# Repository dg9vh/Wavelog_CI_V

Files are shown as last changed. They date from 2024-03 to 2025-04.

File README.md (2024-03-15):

# Wavelog_CI_V
image of configuration dialog on ESP32-webserver

## Introduction
This is a CI-V Connector for Wavelog that can be running on an ESP32 developer board.

## Needed hardware
* ESP 32 board
* 3,5 mm jack plug
* some wire
* diode
* 1x 4k7 resistor
* 1x 10k resistor

How a prototype of a pcb with ESP32 can look like

On the image above you see a prototype built on a perforated grid circuit board.

## Wiring schedule
[Schematics.pdf](/Documents/Schematics.pdf)

## Features
This connects via CI-V to your Icom Transceiver (e.g. IC-7300) on the 3,5 mm jack plug port.
From there it reads following measurements:
* Working frequency
* Working mode
* Working rf-power-level

This values are transported to the radio hardware API of Wavelog (Cloudlog also works) and
there this data can be used for logging purpose.

Also this CI-V Connector is presenting a rudimentary XML-RPC service on port 12345 to be used by 
CloudLogOffline by DL9MJ - you will find this at https://github.com/myzinsky/cloudLogOffline

## Prerequisites
To have this working properly, you need to have your transceiver in "transceive = on"-mode for 
CI-V. Also it should be configured for 19200 baud on the serial output (not on USB-port!).

## Starting from Scratch
First time you start this code (or every time until your local WiFi-network is configured, the
ESP32 starts up with an ad-hoc-wlan with the name "Wavelog_CI_V_AP" and the pre-shared key
12345678 to connect to the ESP32 in order to configure the production WiFi-network it should
connect to.

This is done by connecting to this WiFi-network with a client (phone, tablet, notebook, pc) and 
open the configuration site http://192.168.4.1 to chose your network to use. Enter your PSK and 
then the ESP32 connects to your WiFi. It should optain an ip-address in your LAN via DHCP and 
would listen on the new ip-address with a configuration dialog.

On this dialog you configure the URL of your wavelog installation (for example http://wavelog.dg9vh.de)
and the API-endpoint (for example /index.php/api/radio). Also the Wavelog API Key is needed beneath
the CI-V address of your transceiver (for example 0x94 for an IC-7300).

Save this and be ready to rumble :-)

## How it's working?
From now on every change of one of the parameters mentioned above this would be transported to
your wavelog instance via the API to be available for logging.

## Credits
Some parts of this code (for example fundamentals of the CI-V-communication) where taken from 
Patric (DF7ZZ) and his "Antennenumschalter ESP32"-code. So thank you Patric for your inspirations!

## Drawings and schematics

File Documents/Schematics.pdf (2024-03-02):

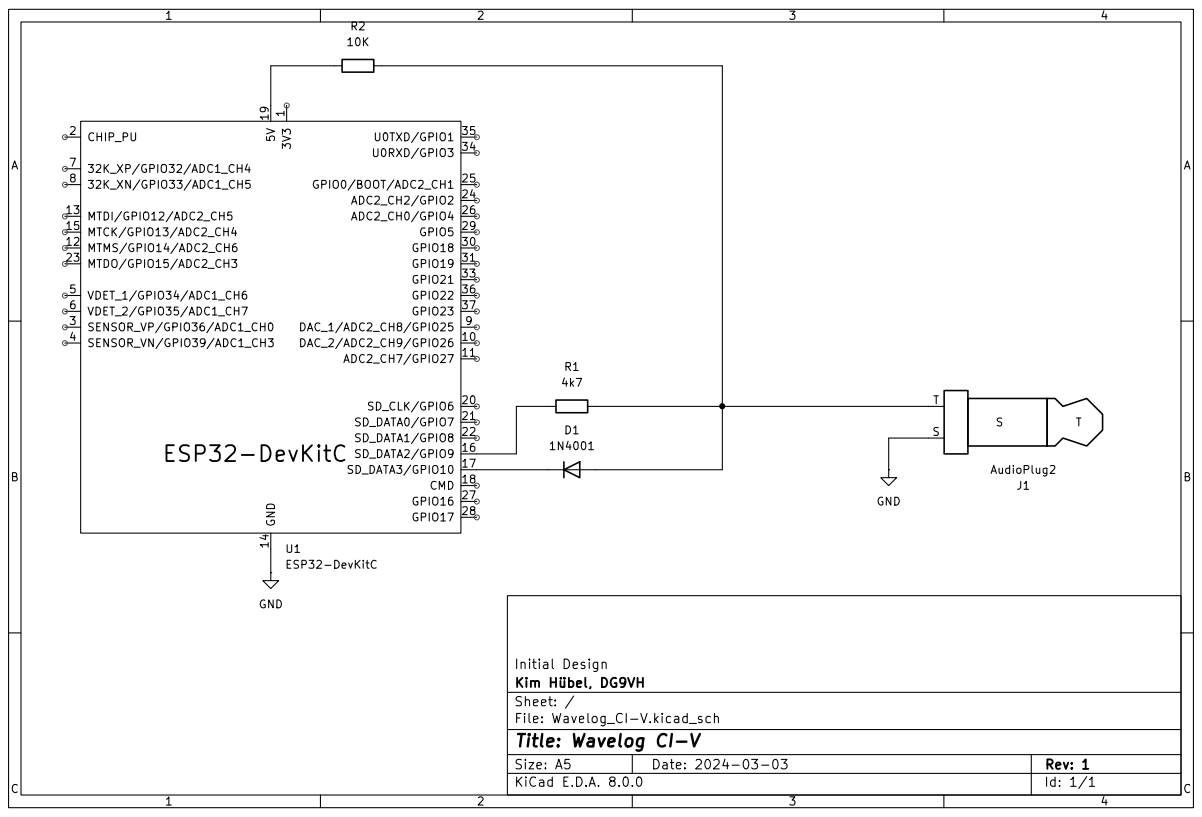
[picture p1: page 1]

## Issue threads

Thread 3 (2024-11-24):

Erweiterung IC-9xxx

tbegerow, 2024-11-24:
Moin Kim,
Danke erstmal für die geniale Importmöglichkeit zu WaveLog. Ich war mal so frei und habe deinen Sketch um die Geräte IC-9100 und IC-9700 erweitert, habe aber ein paar Schwierigkeiten den Mode "DV" zu implementieren. Kannst/magst du dir das vielleicht mal anschauen?
`

 #include <ArduinoJson.h>
#include <HTTPClient.h>
#include <WiFiManager.h>
#include <WebServer.h>
#include <SPIFFS.h>
#include <ESPmDNS.h>

const int numParams = 4; // number of  parameters
String params[numParams] = {"", "", "", ""}; // initialization of parameters
WebServer server(80);
WebServer XMLRPCserver(12345);

unsigned long time_current_baseloop;
unsigned long time_last_baseloop;
#define BASELOOP_TICK 5000 // = 5 seconds

unsigned long frequency = 0;
float power = 0.0;
String mode_str = "";

unsigned long old_frequency = 0;
float old_power = 0.0;
String old_mode_str = "";

// ICOM coms variables
const byte TERM_address(0xE0); // Identifies the terminal (ESP32)
const byte startMarker = 0xFE;  // Indicates where the icom signal string starts
const byte endMarker = 0xFD;    // Indicates where the icom signal string ends

 const char* civ_options[][2] = { // List of names for select-options in config-page
    {"0", "IC-7300 (94h)"},
    {"1", "IC-7200 (76h)"},
    {"2", "IC-7100 (88h)"},
    {"3", "IC-7000 (70h)"},
    {"4", "IC-7410 (80h)"},
    {"5", "IC-9100 (7Ch)"},
    {"6", "IC-9700 (A2h)"}
  };

const byte civ_addresses[] = { // corresponding list of CI-V-Adresses to list above
    0x94,
    0x76,
    0x88,
    0x70,
    0x80,
    0x7C,
    0xA2
  };

const int maxDataLength = 16;
byte receivedData[maxDataLength];  // Array for the recieved data bytes
int dataIndex = 0;                 // Pointer into the data array
bool newData2 = false;             // Set to true when a new data-array has been received
const uint8_t qrg_query[] = {0x03};
const uint8_t mode_query[] = {0x04};
const uint8_t power_query[] = {0x14, 0x0A};
size_t qrg_query_length = sizeof(qrg_query) / sizeof(qrg_query[0]);
size_t mode_query_length = sizeof(mode_query) / sizeof(mode_query[0]);
size_t power_query_length = sizeof(power_query) / sizeof(power_query[0]);

String buffer;
DynamicJsonDocument jsonDoc(512);

void connectToWifi() {
  // Create WiFiManager object
  WiFiManager wfm;

  // Supress Debug information
  wfm.setDebugOutput(false);

  // Remove any previous network settings
  //wfm.resetSettings();

  if (!wfm.autoConnect("Wavelog_CI_V_AP", "12345678")) { // Ad-Hoc-WLAN as fallback to configure production WLAN
    // Did not connect, print error message
    Serial.println("failed to connect and hit timeout");

    // Reset and try again
    ESP.restart();
    delay(1000);
  }
}

void sendCIVQuery(const uint8_t *commands, size_t length) {
  newData2 = false;
  Serial2.write(startMarker);  // always twice 0xFE in the beginning
  Serial2.write(startMarker);
  Serial2.write(civ_addresses[params[3].toInt()]);
  Serial2.write(TERM_address);
  Serial2.write(commands, length);
  Serial2.write(endMarker);

  Serial.println(F("Query sent"));
}

void getpower() {
  sendCIVQuery(power_query, power_query_length);
}

void getqrg() {
  sendCIVQuery(qrg_query, qrg_query_length);
}

void getmode() {
  sendCIVQuery(mode_query, mode_query_length);
}

void geticomdata() {
  while (Serial2.available() > 0 && newData2 == false) {
    byte currentByte = Serial2.read();
    if (currentByte == startMarker) {
      dataIndex = 0;
    } else if (currentByte == endMarker) {
      newData2 = true;
    } else {
      if (dataIndex < maxDataLength) {
        receivedData[dataIndex] = currentByte;
        dataIndex++;
      }
    }
  }
}

int bcd2Dec(int bcdValue) {
    int units = bcdValue & 0xF;  // Untere 4 Bits
    int tens = (bcdValue >> 4) & 0xF;  // Obere 4 Bits

    return tens * 10 + units;
}

void calculateQRG() {
  uint8_t GHZ = 0, MHZ = 0, KHZ = 0, HZ = 0, mHZ = 0;
  uint32_t t_QRG = 0;
  GHZ = bcd2Dec(receivedData[7]);           // 1GHz & 100Mhz
  MHZ = bcd2Dec(receivedData[6]);           // 10Mhz & 1Mhz
  KHZ = bcd2Dec(receivedData[5]);           // 100Khz & 10KHz
  HZ = bcd2Dec(receivedData[4]);         // 1Khz & 100Hz

  t_QRG = ((GHZ * 1000000) + (MHZ * 10000) + (KHZ * 100) + (HZ * 1));  // QRG variable stores frequency in GMMMkkkH format - Frequ divided by 100
  frequency = t_QRG*100;
}

void calculateMode() {
  uint8_t mode_int = receivedData[3];
  switch (mode_int) {
    case 0:
      mode_str = "LSB";
      break;
    case 1:
      mode_str = "USB";
      break;
    case 2:
      mode_str = "AM";
      break;
    case 3:
      mode_str = "CW";
      break;
    case 4:
      mode_str = "RTTY";
      break;
    case 5:
      mode_str = "FM";
      break;
    case 6:
      mode_str = "WFM";
      break;
    case 7:
      mode_str = "CW-R";
      break;
    case 8:
      mode_str = "RTTY-R";
      break;
    case 17:
      mode_str = "DV";
      break;
  }
}

void processReceivedData(void) {
  // first of all starting with the received command as debug on serial console output (e.g. Arduino Serial Monitor)
  Serial.print(F("RX: "));
  for (int i =0; i < maxDataLength; ++i) {
    if (receivedData[i] < 0X0F)
      Serial.print(F("0"));
    Serial.print(receivedData[i], HEX);
    Serial.print(F(" "));
  }
  Serial.println();

  if ((receivedData[0] == 0x00 || receivedData[0] == 0xE0)) { // broadcast to all (0x00), reply to terminal (0xE0)
    switch(receivedData[2]) {
      case 0x0: { // reply at broadcast
        calculateQRG();
        break;
      }
      case 0x1: { // reply at broadcast
        calculateMode();
        break;
      }
      case 0x3: { // reply to terminal on query
        calculateQRG();
        break;
      }
      case 0x4: { // reply to terminal on query
        calculateMode();
        break;
      }
      case 0x14: {
        power = ((receivedData[4]) * 100 + bcd2Dec(receivedData[5])) / 2.55;
        break;
      }
    }
  }
}

void create_json(unsigned long frequency, String mode, float power) {
  jsonDoc.clear();
  jsonDoc["radio"] = String(civ_options[params[3].toInt()][1]) + " Wavelog CI-V";
  jsonDoc["frequency"] = frequency;
  jsonDoc["mode"] = mode;
  jsonDoc["power"] = power;
  jsonDoc["downlink_freq"] = 0;
  jsonDoc["uplink_freq"] = 0;
  jsonDoc["downlink_mode"] = 0;
  jsonDoc["uplink_mode"] = 0;
  jsonDoc["key"] = params[2];
  serializeJson(jsonDoc, buffer);
}

void post_json() {
  HTTPClient http;
    http.begin(params[0] + params[1]); // Endpoint of REST-API on the Wavelog-webserver

    // set content-type as JSON
    http.addHeader("Content-Type", "application/json");
    // send post-request with data
    Serial.println(buffer); // debug output of json-string
    int httpResponseCode = http.POST(buffer);

    if (httpResponseCode > 0) {
      Serial.print(F("HTTP-state: "));
      Serial.println(httpResponseCode);

      String response = http.getString();
      Serial.println(response);
      old_mode_str = mode_str;
      old_frequency = frequency;
      old_power = power;
    } else {
      Serial.print(F("Error on sending the post-request. HTTP-state: "));
      Serial.println(httpResponseCode);
    }
    http.end();
}

void handleRoot() {
  String html = "<!DOCTYPE html>";
  html += "<html>";
  html += "<head>";
  html += "<meta charset=\"UTF-8\">";
  html += "<meta name=\"viewport\" content=\"width=device-width, initial-scale=1.0\">";
  html += "<title>ESP32 Configuration</title>";
  html += "<style>";
  html += "body { font-family: Arial, sans-serif; }";
  html += ".container { max-width: 400px; margin: 0 auto; padding: 20px; }";
  html += "input[type='text'] { width: 100%; padding: 10px; margin: 5px 0; }";
  html += "input[type='submit'] { width: 100%; padding: 10px; margin-top: 10px; background-color: #4CAF50; color: white; border: none; }";
  html += ".btn-reboot { width: 100%; padding: 10px; margin-top: 10px; background-color: #FF0000; color: white; border: none; }";
  html += "input[type='submit']:hover { background-color: #45a049; }";
  html += "</style>";
  html += "</head>";
  html += "<body>";
  html += "<div class=\"container\">";
  html += "<h1>ESP32 Wavelog CI-V Configuration</h1>";
  html += "<form action='/save' method='post'>";
  html += "<label for='wavelogUrl'>Wavelog URL:</label><br>";
  html += "<input type='text' id='wavelogUrl' name='wavelogUrl' value='" + params[0] + "'><br>";
  html += "<label for='wavelogApiEndpoint'>Wavelog API Endpoint:</label><br>";
  html += "<input type='text' id='wavelogApiEndpoint' name='wavelogApiEndpoint' value='" + params[1] + "'><br>";
  html += "<label for='wavelogApiKey'>Wavelog API Key:</label><br>";
  html += "<input type='text' id='wavelogApiKey' name='wavelogApiKey' value='" + params[2] + "'><br>";
  html += "<label for='TrxAddress'>Trx Address:</label><br>";
  html += "<select id='TrxAddress' name='TrxAddress'>";

  for (int i = 0; i < sizeof(civ_options) / sizeof(civ_options[0]); ++i) {
    String optionHTML = "<option value='" + String(civ_options[i][0]) + "'";
    optionHTML += (params[3].toInt() == atoi(civ_options[i][0]) ? " selected" : "");
    optionHTML += ">" + String(civ_options[i][1]) + "</option>";
    html += optionHTML;
  }
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
dg9vh, 2024-11-24:
Hi Thorsten,

zunächst einmal danke für deine Anregung, die beiden TRX in die Liste aufzunehmen... du kannst das gerne, wenn's soweit funktioniert, in einen PR packen und hier eintüten, ich werde das zügig mergen :-)

Was den Mode "DV" angeht, ist es ja so, dass wir hier in der Funktion, wo die Codes auf die Modes abgebildet werden, eigentlich auf die ADIF-Modes abbilden wollen.

Für DV wäre dann hier eine Kombi aus Mode und Submode umzusetzen:

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

Bei der Gelegenheit hab ich auch gerade gesehen, dass ich oben ein WFM abbilde, was es wohl im ADIF nicht gibt :-) Fällt aber praktisch auch erstmal nicht ins Gewicht, weil wir Funkamateure kein WFM machen :-)

Man müsste mal schauen, wie die API von Wavelog das mit DV haben will, ob es hier reicht, den Submode zu bringen als Mode oder ob hier Mode und Submode geliefert werden müssen.

Ich mach mich da mal schlau...

Was die PINs angeht, weiß ich nicht, wieso da auf einmal was anderes ist. Ich weiß, dass ich hier mehrere ESP32 verschiedener Herkunft im Einsatz hatte, evtl. ist die Schaltung auf nem anderen Model basierend...

73 de Kim
DG9VH

dg9vh, 2024-11-24:
Hallo Thorsten,

ich habe jetzt mal getestet, wenn du

case 17:
mode_str = "DV";
break;

tauschst gegen

case 17:
mode_str = "DSTAR";
break;

dann passt es :-)

ich werde jetzt mal die Änderungen im Code vornehmen, du musst keinen Pull-Request machen... solltest aber, wenn der Commit durch ist, mal testen :-)

tbegerow, 2024-11-24:
Hallo Kim,

danke, werde ich morgen früh gleich mal ausprobieren. ;-)
Auch fürs gleich Einchecken, ich hätte mich zugegebenermaßen da erstmal einarbeiten müssen…
73 und einen schönen Abend:-)

dg9vh, 2024-11-24:
Kein Problem :-) ging relativ fix.

tbegerow, 2024-11-25:
Moin Kim,
ich konnte gerade den neuen Sketch mal einspielen, leider zeigt er nach wie vor den DV-Mode nicht an (siehe Screenshots)
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
Ich habe auch mal einen Screenshot von der Konsolenausgabe gemacht:

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
Nach dem Neustart des ESP schreibt er mir "N/A" ins Wavelog, bis ich den Mode wechsel. Wechsel ich wieder zurück beispielsweise von FM auf DV (Anzeige im Gerät) dann bleibt er seltsamerweise auf "FM" stehen.
Ich fürchte ich bin hier mit meinen "Programmierkenntnissen" nahe dem Ende angelangt, mir fehlt aber auch die zündende Idee wo ich ansetzen soll...:-/ Hast du noch eine Idee?
73 de Thorsten DG5YIM

dg9vh, 2024-11-25:
Hi Probier mal den neuen commit - ich vermute, wir sind beide darauf reingefallen, dass es kein integer ist, was da über die Serielle reinkommt, sondern ein hex...

tbegerow, 2024-11-26:
Heureka und Ihhh, wie fies :-P
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
Aber es hat funktioniert. Nun muss ich nur noch eine kleine Platine "designen" ;-)
Ich danke dir für das schnelle Fixen.
73 de Thorsten DG5YIM

Closed 2024-11-24.

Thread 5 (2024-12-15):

HamClock direkt (Verständnisfrage)

tbegerow, 2024-12-15:
Moin Kim,
ich versuche gerade die HamClock per flrig direkt anzusprechen, bekomme allerdings ein "FLRIG PTT query failed".
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
Die XML-RPC-Schnittstelle, gibt die nur das wieder aus, was man im Sketch abfragt bzw. was der Monitor-Output auch ausgibt?
Oder werden alle CI-V-Daten direkt durchgereicht? Tnx fer Info :-)
73 de Thorsten DG5YIM

dg9vh, 2024-12-15:
Hi, es wird nur das über die XML-RPC-Schnittstelle übergeben, was im Sketch ersichtlich ist - das ist auch nur das, was CloudlogOffline braucht... die FLRIG-Schnittstelle war nur eingebaut worden, um CloudlogOffline damit zu befüllen. Kann kann damit nicht FLRIG abfragen.

tbegerow, 2024-12-16:
Moin,
das hatte ich schon fast befürchtet bzw. mir fast gedacht. Hatte mich auch mal daran versucht, den TRX-State (Cmd 1C 00) einzubauen, aber das State hat sich nicht mit geändert.
FLRIG wollte ich damit auch nicht abfragen, sondern den State TX oder RX direkt in der HamClock anzeigen bzw. den XML-RPC direkt vom ESP32 abfragen, ohne den Umweg über den PC  gehen zu müssen.
Nebenbei: Ich habe mir mal ein Platinchen hierfür erstellt, kann/darf ich das hier auch mal commiten?
73 de Thorsten DG5YIM

dg9vh, 2024-12-16:
Moin Thorsten,

gerne darfst du dich am Code versuchen und die von dir gewünschte Funktion mit implementieren - am Besten erst mal in nem eigenen Fork zum testen, dass es sauber funktioniert und keine komischen Einflüsse hat...

Was die Platine angeht, kannst du gerne einen commit machen, vielleicht in ein eigenes Unterverzeichnis PCB oder sowas?

tnx!
73 de Kim

tbegerow, 2024-12-17:
So, die Platine ist upgedatet und eingepflegt ;-) Hab noch mal einen kleinen Umschalter hinzu gefügt, um die Abfrage am Klinkenstecker anzupassen. Beim ID-5100 ist er nämlich auf der mittleren Position, nicht an der Spitze.
An den Code mache ich mich dann allerdings erst ab morgen Abend, denn wir haben OV-Abend, da wollte ich dieses kleine Gimmick mal vorführen und nicht meinen letzten ESP jetzt mit Basteleien "zerschießen" ;-)
Danke für die Info
73 de Thorsten DG5YIM

dg9vh, 2024-12-17:
Nur nichts überstürzen :-)

tbegerow, 2024-12-19:
Moin Kim,
Ich habe mich heute Morgen mal an den Code gemacht, habe aber das Gefühl etwas Essentielles übersehen zu haben.
Kannst/magst du mal über den Fork schauen?
Tnx et 73 de Thorsten DG5YIM

tbegerow, 2024-12-19:
https://github.com/tbegerow/Wavelog_CI_V

dg9vh, 2024-12-19:
Ohne jetzt die Zeit gehabt zu haben, einen Test zu machen damit, sieht der Code mal gut aus soweit... konnte jetzt erstmal so nix sehen, was mir fehlte... Hast die Sache ja "analog" zum "getMode" durchgezogen... das sollte ja dann passen...

Mal schauen, wie die Zeit es ergibt, evtl. schaffe ich heute mal, das auf meinen ESP drauf zu spielen und zu testen mit dem IC7300... der sollte die PTT ja auch ausliefern, denke ich.

tbegerow, 2025-01-06:
Moin Kim, erstmal frohe Weihnachten nachträglich und frohes neues Jahr ;-)
Ich habe zwischen den Feiertagen etwas Zeit gefunden mich nochmal in den Code rein zu fuchsen: Wenn ich ´getptt´ in den Loop 5 sec. rein setze dann fragt er brav alle 5 Sekunden den PTT-Status ab, jedoch nicht die direkte Änderung vom Funkgerät aus dem CI-V.... was übersehe ich? Hast du noch eine Idee/ einen Tipp?  tnx et
73 de Thorsten DG5YIM

dg9vh, 2025-01-06:
Das ist korrekt - es wird ja auch nur alle 5 Sekunden gepollt und nicht der Traffic ausgewertet, der sonst kommt, um nicht die API zu spammen.

tbegerow, 2025-01-06:
So hatte ich das auch verstanden, bzw. wird da ja das ´getpower´mit "aktiv" ausgewertet, weil dort wohl keine Statusänderung vom Funkgerät selbst kommt.
Aber die PTT sollte ja schon in Echtzeit ausgewertet werden, oder habe ich da einen Denkfehler?
Die Frequenzänderung bzw. der Mode wird ja direkt übertragen, der Status der PTT auch? tnx fer Info :-)

dg9vh, 2025-01-06:
Ich vermute, dass Funkgerät, wenn es auf TRCV=on steht, feuert den Event auch ins CI-V rein, nur mein Code wertet das nicht aus :-)

Dafür war er nicht konzipiert.

dg9vh, 2025-01-06:
Hi, ja, das Funkgerät, wenns so eingestellt ist, schreibt die Änderungen auf die CI-V-Schnittstelle... die interessieren mich aber nicht in meinem Sketch, sondern ich rufe die per Polling eigenständig ab, weil nur das ne sichere Methode ist. Nicht jeder hat Transceive = on stehen. Deswegen bekomme ich die PTT-Events in meinem Sketch auch nur alle 5 Sekunden mit.

Ich hab mir deinen Code mal angeschaut, kann ihn aber nicht beurteilen, ob er funktioniert oder nicht... sorry, dafür bin ich auch nicht Profi genug in dem Thema...

Leider kann ich dir da auch nicht wirklich helfen. Du kannst dir meinen Code als Basis nehmen und rumprobieren, keine Frage, aber so richtig weiter helfen damit kann ich dir leider nicht.

tbegerow, 2025-01-06:
Alles klar und danke, das hat mir doch schon etwas geholfen :-) Ich schau mir das bei Gelegenheit noch mal in Ruhe an. ;-) ...aber nicht mehr heute, ist schon dunkel draußen... :-D
73 de Thorsten DG5YIM

Closed 2025-01-06.

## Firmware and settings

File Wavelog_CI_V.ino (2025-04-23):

#include <ArduinoJson.h>
#include <HTTPClient.h>
#include <WiFiManager.h>
#include <WebServer.h>
#include <SPIFFS.h>
#include <ESPmDNS.h>

const int numParams = 4; // number of  parameters
String params[numParams] = {"", "", "", ""}; // initialization of parameters
WebServer server(80);
WebServer XMLRPCserver(12345);

unsigned long time_current_baseloop;
unsigned long time_last_baseloop;
unsigned long time_last_update;
#define BASELOOP_TICK 5000 // = 5 seconds
#define DEBOUNCE_TIME 1500 // = 1,5sec. process ONLY if TRX has settled

unsigned long frequency = 0;
float power = 0.0;
String mode_str = "";

unsigned long old_frequency = 0;
float old_power = 0.0;
String old_mode_str = "";

// ICOM coms variables
const byte TERM_address(0xE0); // Identifies the terminal (ESP32)
const byte startMarker = 0xFE;  // Indicates where the icom signal string starts
const byte endMarker = 0xFD;    // Indicates where the icom signal string ends

 const char* civ_options[][2] = { // List of names for select-options in config-page
    {"0", "IC-7300 (94h)"},
    {"1", "IC-7200 (76h)"},
    {"2", "IC-7100 (88h)"},
    {"3", "IC-7000 (70h)"},
    {"4", "IC-7410 (80h)"},
    {"5", "IC-9100 (7Ch)"},
    {"6", "IC-9700 (A2h)"},
    {"7", "ID-5100 (8Ch)"}
  };

const byte civ_addresses[] = { // corresponding list of CI-V-Adresses to list above
    0x94,
    0x76,
    0x88,
    0x70,
    0x80,
    0x7C,
    0xA2,
    0x8C
  };

const int maxDataLength = 16;
byte receivedData[maxDataLength];  // Array for the recieved data bytes
int dataIndex = 0;                 // Pointer into the data array
bool newData2 = false;             // Set to true when a new data-array has been received
const uint8_t qrg_query[] = {0x03};
const uint8_t mode_query[] = {0x04};
const uint8_t power_query[] = {0x14, 0x0A};
size_t qrg_query_length = sizeof(qrg_query) / sizeof(qrg_query[0]);
size_t mode_query_length = sizeof(mode_query) / sizeof(mode_query[0]);
size_t power_query_length = sizeof(power_query) / sizeof(power_query[0]);

String buffer;
DynamicJsonDocument jsonDoc(512);

void connectToWifi() {
  // Create WiFiManager object
  WiFiManager wfm;
 
  // Supress Debug information
  wfm.setDebugOutput(false);
 
  // Remove any previous network settings
  //wfm.resetSettings();
 
  if (!wfm.autoConnect("Wavelog_CI_V_AP", "12345678")) { // Ad-Hoc-WLAN as fallback to configure production WLAN
    // Did not connect, print error message
    Serial.println("failed to connect and hit timeout");
 
    // Reset and try again
    ESP.restart();
    delay(1000);
  }
}

void sendCIVQuery(const uint8_t *commands, size_t length) {
  newData2 = false;
  Serial2.write(startMarker);  // always twice 0xFE in the beginning
  Serial2.write(startMarker);
  Serial2.write(civ_addresses[params[3].toInt()]);
  Serial2.write(TERM_address);
  Serial2.write(commands, length);
  Serial2.write(endMarker);

  Serial.println(F("Query sent"));
}

void getpower() {
  sendCIVQuery(power_query, power_query_length);
}

void getqrg() {
  sendCIVQuery(qrg_query, qrg_query_length);
}

void getmode() {
  sendCIVQuery(mode_query, mode_query_length);
}

void geticomdata() {
  while (Serial2.available() > 0 && newData2 == false) {
    byte currentByte = Serial2.read();
    if (currentByte == startMarker) {
      dataIndex = 0;
    } else if (currentByte == endMarker) {
      newData2 = true;
    } else {
      if (dataIndex < maxDataLength) {
        receivedData[dataIndex] = currentByte;
        dataIndex++;
      }
    }  
  }
}

int bcd2Dec(int bcdValue) {
    int units = bcdValue & 0xF;  // Untere 4 Bits
    int tens = (bcdValue >> 4) & 0xF;  // Obere 4 Bits

    return tens * 10 + units;
}

void calculateQRG() {
  uint8_t GHZ = 0, MHZ = 0, KHZ = 0, HZ = 0, mHZ = 0;
  uint32_t t_QRG = 0;
  GHZ = bcd2Dec(receivedData[7]);           // 1GHz & 100Mhz
  MHZ = bcd2Dec(receivedData[6]);           // 10Mhz & 1Mhz
  KHZ = bcd2Dec(receivedData[5]);           // 100Khz & 10KHz
  HZ = bcd2Dec(receivedData[4]);         // 1Khz & 100Hz
  
  t_QRG = ((GHZ * 1000000) + (MHZ * 10000) + (KHZ * 100) + (HZ * 1));  // QRG variable stores frequency in GMMMkkkH format - Frequ divided by 100
  frequency = t_QRG*100;
}

void calculateMode() {
  uint8_t mode_int = receivedData[3];
  switch (mode_int) {
    // Abbildung erfolgt gemäß der ADIF-Modes, daher z.B. CW und CW-R als CW, ebenso RTTY und RTTY-R
    case 0:
      mode_str = "LSB";
      break;
    case 1:
      mode_str = "USB";
      break;
    case 2:
      mode_str = "AM";
      break;
    case 3:
      mode_str = "CW";
      break;
    case 4:
      mode_str = "RTTY";
      break;
    case 5:
      mode_str = "FM";
      break;
    case 6:
      mode_str = "FM";
      break;
    case 7:
      mode_str = "CW";
      break;
    case 8:
      mode_str = "RTTY";
      break;
    case 23:
      mode_str = "DSTAR";
      break;
  }
}

void processReceivedData(void) {
  // first of all starting with the received command as debug on serial console output (e.g. Arduino Serial Monitor)
  Serial.print(F("RX: "));
  for (int i =0; i < maxDataLength; ++i) {
    if (receivedData[i] < 0X0F)
      Serial.print(F("0"));
    Serial.print(receivedData[i], HEX);
    Serial.print(F(" "));
  }
  Serial.println();
    
  if ((receivedData[0] == 0x00 || receivedData[0] == 0xE0)) { // broadcast to all (0x00), reply to terminal (0xE0)
    switch(receivedData[2]) {
      case 0x0: { // reply at broadcast
        calculateQRG();
        break;
      }
      case 0x1: { // reply at broadcast
        calculateMode();
        break;
      }
      case 0x3: { // reply to terminal on query
        calculateQRG();
        break;
      }
      case 0x4: { // reply to terminal on query
        calculateMode();
        break;
      }
      case 0x14: {
        power = ((receivedData[4]) * 100 + bcd2Dec(receivedData[5])) / 2.55;
        break;
      }
    }
  }
}

void create_json(unsigned long frequency, String mode, float power) {  
  jsonDoc.clear();  
  jsonDoc["radio"] = String(civ_options[params[3].toInt()][1]) + " Wavelog CI-V";
  jsonDoc["frequency"] = frequency;
  jsonDoc["mode"] = mode;
  jsonDoc["power"] = power;
  jsonDoc["downlink_freq"] = 0;
  jsonDoc["uplink_freq"] = 0;
  jsonDoc["downlink_mode"] = 0;
  jsonDoc["uplink_mode"] = 0;
  jsonDoc["key"] = params[2];
  serializeJson(jsonDoc, buffer);
}

void post_json() {
  HTTPClient http;
    http.begin(params[0] + params[1]); // Endpoint of REST-API on the Wavelog-webserver

    // set content-type as JSON
    http.addHeader("Content-Type", "application/json");
    // send post-request with data
    Serial.println(buffer); // debug output of json-string
    int httpResponseCode = http.POST(buffer);

    if (httpResponseCode > 0) {
      Serial.print(F("HTTP-state: "));
      Serial.println(httpResponseCode);

      String response = http.getString();
      Serial.println(response);
      old_mode_str = mode_str;
      old_frequency = frequency;
      old_power = power;
    } else {
      Serial.print(F("Error on sending the post-request. HTTP-state: "));
      Serial.println(httpResponseCode);
    }
    http.end(); 
}

void handleTrx() {
  jsonDoc.clear();  
  jsonDoc["qrg"] = frequency;
  jsonDoc["mode"] = mode_str;
  serializeJson(jsonDoc, buffer);
  server.send(200, "application/json", buffer);
}

void handleRoot() {
  String html = "<!DOCTYPE html>";
  html += "<html>";
  html += "<head>";
  html += "<meta charset=\"UTF-8\">";
  html += "<meta name=\"viewport\" content=\"width=device-width, initial-scale=1.0\">";
  html += "<title>ESP32 Configuration</title>";
  html += "<style>";
  html += "body { font-family: Arial, sans-serif; }";
  html += ".container { max-width: 400px; margin: 0 auto; padding: 20px; }";
  html += "input[type='text'] { width: 100%; padding: 10px; margin: 5px 0; }";
  html += "input[type='submit'] { width: 100%; padding: 10px; margin-top: 10px; background-color: #4CAF50; color: white; border: none; }";
  html += ".btn-reboot { width: 100%; padding: 10px; margin-top: 10px; background-color: #FF0000; color: white; border: none; }";
  html += "input[type='submit']:hover { background-color: #45a049; }";
  html += "</style>";
  html += "</head>";
  html += "<body>";
  html += "<div class=\"container\">";
  html += "<h1>ESP32 Wavelog CI-V Configuration</h1>";
  html += "<p>Current QRG/Mode from CI-V:&nbsp;<span id='qrg'></span>&nbsp;/&nbsp;<span id='mode'></span></p>";
  html += "<form action='/save' method='post'>";
  html += "<label for='wavelogUrl'>Wavelog URL:</label><br>";
  html += "<input type='text' id='wavelogUrl' name='wavelogUrl' value='" + params[0] + "'><br>";
  html += "<label for='wavelogApiEndpoint'>Wavelog API Endpoint:</label><br>";
  html += "<input type='text' id='wavelogApiEndpoint' name='wavelogApiEndpoint' value='" + params[1] + "'><br>";
  html += "<label for='wavelogApiKey'>Wavelog API Key:</label><br>";
  html += "<input type='text' id='wavelogApiKey' name='wavelogApiKey' value='" + params[2] + "'><br>";
  html += "<label for='TrxAddress'>Trx Address:</label><br>";
  html += "<select id='TrxAddress' name='TrxAddress'>";

  for (int i = 0; i < sizeof(civ_options) / sizeof(civ_options[0]); ++i) {
    String optionHTML = "<option value='" + String(civ_options[i][0]) + "'";
    optionHTML += (params[3].toInt() == atoi(civ_options[i][0]) ? " selected" : "");
    optionHTML += ">" + String(civ_options[i][1]) + "</option>";
    html += optionHTML;
  }

  html += "</select><br>";
  html += "<input type='submit' value='Save'>";
  html += "</form>";
  html += "<form action='/reboot' method='post'>";
  html += "<button type='submit' class='btn-reboot'>Reboot ESP32</button>";
  html += "</form>";
  html += "</div>";
  html += "<script>";
  html += R"JS(
setInterval(function() {
  fetch('/trx')
    .then(response => response.json())
    .then(data => {
      document.getElementById('qrg').textContent = (data.qrg/1000)+'kHz';
      document.getElementById('mode').textContent = data.mode;
    })
    .catch(error => {
      console.error('Fetch error:', error);
    });
}, 1000);
)JS";
  html += "</script></body></html>";

  server.send(200, "text/html", html);
}

void loadParametersFromSPIFFS() {
  for (int i = 0; i < numParams; ++i) {
    File file = SPIFFS.open("/param" + String(i) + ".txt", "r");
    if (!file) {
      Serial.println("Failed to open file for reading");
      return;
    }
    params[i] = file.readStringUntil('\n');
    file.close();
  }
}

void saveParametersToSPIFFS() {
  for (int i = 0; i < numParams; ++i) {
    File file = SPIFFS.open("/param" + String(i) + ".txt", "w");
    if (!file) {
      Serial.println("Failed to open file for writing");
      return;
    }
    file.print(params[i]);
    file.close();
  }
}

void handleSave() {
  params[0] = server.arg("wavelogUrl");
  params[1] = server.arg("wavelogApiEndpoint");
  params[2] = server.arg("wavelogApiKey");
  params[3] = server.arg("TrxAddress");

  saveParametersToSPIFFS();

  server.sendHeader("Location", "/", true);
  server.send(302, "text/plain", "");
}

void handleReboot() {
    ESP.restart();
}

String rig_get_vfo() {
  return String(frequency);
}

String rig_get_mode() {
  return mode_str;
}

void handleRPC() {
  // processing XML-RPC-request
  if (XMLRPCserver.arg(0).indexOf("<methodName>rig.get_vfo</methodName>") != -1) {
    String response = rig_get_vfo();
    XMLRPCserver.send(200, "text/xml", "<methodResponse><params><param><value>" + response + "</value></param></params></methodResponse>");
  } else if (XMLRPCserver.arg(0).indexOf("<methodName>rig.get_mode</methodName>") != -1) {
    String response = rig_get_mode();
    XMLRPCserver.send(200, "text/xml", "<methodResponse><params><param><value>" + response + "</value></param></params></methodResponse>");
  } else {
    XMLRPCserver.send(400, "text/plain", "Unknown method");
  }
}

void setup() {
  Serial.begin(115200);  // Serial console
  Serial2.begin(19200, SERIAL_8N1, 16, 17);  // ICOM CI-V
  delay(1000);
  Serial.println(F(""));
  Serial.println(F("Booting Sketch..."));
  MDNS.begin("esp32-ci-v");

  if (!SPIFFS.begin(true)) {
    Serial.println("SPIFFS initialization failed!");
    return;
  }
  
  loadParametersFromSPIFFS();

  Serial.print(F("URL: "));
  Serial.println(params[0]);
  Serial.print(F("Endpoint: "));
  Serial.println(params[1]);
  Serial.print(F("API-Key: "));
  Serial.println(params[2]);
  Serial.print(F("CI-V-Address: "));
  Serial.println(params[3]);
  connectToWifi();

  Serial.print(F("IP-Address: "));
  Serial.println(WiFi.localIP());

  server.on("/", handleRoot);
  server.on("/trx", handleTrx);
  server.on("/save", handleSave);
  server.on("/reboot", handleReboot);
  server.begin();
  Serial.println("HTTP server started");

  // Routing for XML-RPC-requests
  XMLRPCserver.on("/", handleRPC);
  XMLRPCserver.begin();
  Serial.println("XMLRPCserver started");

  delay(1000);
  time_current_baseloop = millis();
  time_last_baseloop = time_current_baseloop;

  if (params[0].length() > 0) {
    getmode();
    if (params[3].toInt() >= 0) 
      geticomdata();
    if (newData2) {
      processReceivedData();
    }
    newData2 = false;
    delay(1000);
    getqrg();
    if (params[3].toInt() >= 0) 
      geticomdata();
    if (newData2) {
      processReceivedData();
    }
    newData2 = false;
    create_json(frequency, mode_str, power);
    post_json();
  }
}

void loop() {
  server.handleClient();
  XMLRPCserver.handleClient();
  if (WiFi.status() == WL_CONNECTED) {
    time_current_baseloop = millis();

    //query tx-power every 5 secs
    if ((time_current_baseloop - time_last_baseloop) > BASELOOP_TICK) {
      getpower();
      time_last_baseloop = time_current_baseloop;
    }
    
    if (params[3].toInt() >= 0) 
      geticomdata();
    if (newData2) {
      time_last_update = millis();
      processReceivedData();
    }
    newData2 = false;
  
    delay(10); 
    if (( mode_str != old_mode_str || frequency != old_frequency || power != old_power) && ((time_current_baseloop-time_last_update)>DEBOUNCE_TIME)) {
      // send json to server
      create_json(frequency, mode_str, power);
      post_json();
    }
  } else {
    Serial.println(F("No connection to your WiFi-network."));
    connectToWifi();
  }
} // end loop

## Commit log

2024-03-02 Create Schematics.pdf
    Added PDF of schematics
2024-03-02 Added link to schematics
2024-03-02 Added GND to ESP32
2024-03-15 Fixing CI-V addresses and adding XML-RPC
    beneath correcting the CI-V address-handling this commit enables the XML-RPC-service to incooperate with CloudLogOffline - https://github.com/myzinsky/cloudLogOffline
    [Wavelog_CI_V.ino]
2024-03-15 Improved WLAN + added Reboot-button
    [Wavelog_CI_V.ino]
2024-11-25 wrong int - 17 was hex :-)
    [Wavelog_CI_V.ino]
2024-12-17 PCB with 3,5mm-Jack
    [Wavelog_CI-V.kicad_pcb]
